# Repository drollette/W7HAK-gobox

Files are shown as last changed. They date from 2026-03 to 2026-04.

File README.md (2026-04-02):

# W7HAK Go Box Telemetry System

A field-deployable amateur radio go box (callsign **W7HAK**) with real-time battery telemetry, environmental monitoring, and a local Grafana dashboard accessible over a USB gadget-mode connection.

---

## Hardware Architecture

| Component | Role |
|---|---|
| Raspberry Pi Zero W | Single-board computer running telemetry daemon, InfluxDB, and Grafana |
| 4S3P 45 Ah LiFePO4 pack | Primary power (nominal 12.8 V, 576 Wh) using 33140-format cells |
| ADS1115 (I2C 0x48) | 16-bit ADC reading four cell-tap voltages via resistor ladder |
| 2x INA226 (I2C 0x40, 0x41) | High-side current/power monitors for solar input and system load |
| DS18B20 (GPIO 4, 1-Wire) | Ambient and cell temperature sensors |
| DC Fuse Block (marine-grade) | Central power distribution with individually fused load circuits |
| RF-silent 12V DC fan | Enclosure cooling, activated by hardware thermal switch |
| Normally-open thermal switch | Ambient temperature failsafe — engages fan at ~45 °C without GPIO control |
| DC-DC Buck-Boost Charge Controller | LTC3780 10A converter tuned to 14.6V CV / 5A CC LiFePO4 profile |

### Power Distribution & Charging

All system power flows from the battery through a single monitored path before reaching the fuse block. An **LTC3780 10A Buck-Boost Converter** allows charging from any unconditioned DC source (12V automotive charger, vehicle accessory port, generic power supply) via an Anderson Powerpole input connector. The LTC3780 is physically calibrated to a **14.6V CV / 5A CC** LiFePO4 charging profile using its onboard potentiometers (see [Charging Calibration](#charging-calibration) below).

```text
                        [External Universal DC Input Port]
                                       |
                                  [15A Fuse]
                                       |
                +---------------------------------------------+
                |     LTC3780 10A Buck-Boost Converter        |
                |   (Tuned to 14.6V CV / 5A CC via Pots)      |
                +---------------------------------------------+
                           |                       |
                     (Positive Out)          (Negative Out)
                           |                       |
                           +-------[ 1000µF ]------+  <-- (Differential Noise Filter)
                           |                       |
                           +-------[ 0.1µF  ]------+  <-- (High-Freq Bypass)
                           |                       |
                           |                       |
                        ===============================
                       ||  Solid Ferrite Bead(s)      ||  <-- (Common-Mode Filter)
                       || (Both wires pass through!)  ||
                        ===============================
                           |                       |
                       [15A Fuse]                  |
                           |                       |
                           v                       |
[4S LiFePO4 Battery] -> [BMS] -> [Main Shunt] <----+ (Negative connects here)
                                       |
                               [25A Main Fuse]
                                       |
    =========================================================================
    ||                        12V DC FUSE BLOCK                            ||
    =========================================================================
          |              |              |                 |
     (10A G90)     (3A Buck/Pi)    (1A Fan)         (1A Telemetry)
```

| Circuit | Fuse | Notes |
|---|---|---|
| Xiegu G90 Transceiver | 10A blade | ~8A peak at 20W transmit |
| Raspberry Pi (12V-to-5V buck converter) | 3A blade | Protects 12V input side of converter |
| RF-silent fan + thermal switch | 1A blade | Fan draws < 0.3A; thermal switch in series |
| Telemetry sensors / microcontrollers | 1A blade | ADS1115, INA226, DS18B20 circuits |

All loads **must** be individually fused on this block. See [wiring_diagrams/WIRING_GUIDE.md](wiring_diagrams/WIRING_GUIDE.md) for complete routing details.

### Universal DC Charging

The system accepts a wide range of DC inputs (10–30V) via an external **Anderson Powerpole** connection on the enclosure panel. This input is routed through a **15A inline fuse** to an **LTC3780 10A Buck-Boost Converter** physically calibrated to a **14.6V CV / 5A CC** LiFePO4 charging profile.

Key design points:

- The LTC3780 output is filtered by a **high-current LC Pi-Filter** that eliminates both differential and common-mode RF switching noise before it reaches the Xiegu G90:
  - **Stage 1 (Differential):** A 1000µF electrolytic capacitor and 0.1µF ceramic capacitor are soldered in parallel directly across the LTC3780 OUT terminals, absorbing voltage ripple and high-frequency spikes.
  - **Stage 2 (Common-Mode):** Both positive and negative output wires pass together through solid ferrite bead(s), suppressing common-mode noise that would otherwise radiate from the cable runs.
- The filtered **positive output** passes through a **15A inline fuse** before connecting to the main positive bus (battery side of the 25A main fuse).
- The filtered **negative output** connects to the **system/load side of the main current shunt** — not directly to the battery terminal. This ensures the System INA226 sees bidirectional current (positive = discharge, negative = charge), enabling the telemetry system to track charge current.
- The LTC3780 is housed in a **3D-printed protective enclosure** lined with **copper foil tape** on the inside surfaces to form a Faraday cage, suppressing radiated emissions.

**The negative output of the LTC3780 must pass through the main shunt. Do not wire it directly to the battery's negative terminal, or the telemetry script will not register the incoming charging current.**

### Thermal Management — RF-Silent Fan & Thermal Switch

An RF-silent 12V DC fan provides enclosure cooling. The fan is controlled entirely in hardware by a **normally-open (NO) thermal switch** wired in series on a dedicated 1A fused circuit from the DC fuse block. When the ambient enclosure temperature reaches approximately **45 °C**, the thermal switch closes and the fan runs.

This design is intentional: the thermal switch acts as an automatic hardware-level failsafe that does **not** require Raspberry Pi GPIO control or any software switching logic. This keeps RF noise from PWM or digital switching to an absolute minimum — critical for a ham radio go box operating on HF.

The DS18B20 ambient temperature sensor (read by `telemetry.py`) monitors the same enclosure environment. When telemetry readings approach 45 °C, the fan should be observed activating independently via the thermal switch.

### Bill of Materials

For a complete list of hardware, sensors, and passive components required to build this system, please see the [Bill of Materials (BOM)](BOM.md).

### Voltage Measurement — Resistor Ladder

The ADS1115 cannot safely measure the full pack voltage directly. A resistor ladder divides each cell-stack tap down to a range the ADC can read. The `telemetry.py` script applies the following multipliers to recover actual stack voltages, then uses subtraction to isolate each cell:

| Channel | Tap | Multiplier |
|---|---|---|
| AIN0 | Cell 1 top | 2.0 |
| AIN1 | Cell 2 top | 3.2 |
| AIN2 | Cell 3 top | 4.3 |
| AIN3 | Cell 4 top (pack +) | 5.7 |

See `/wiring_diagrams/ads1115_resistor_ladder_schematic.svg` for the full schematic.

### Analog Signal Filtering

Each resistor ladder output passes through a hardware RC low-pass filter before reaching the ADS1115 ADC input. This eliminates switching noise from the LTC3780 charger and other RF sources at the hardware level, producing clean readings without aggressive software filtering.

```text
[Battery Cell Tap] or [Shunt Sensor Out]
         |
         | (Raw, noisy analog signal)
         |
         +-----[ 1kΩ Resistor ]-----+---------> To ADC Input Pin / GPIO
                                    |
                                    +---[ 10µF Capacitor ]---+
                                    |                        |
                                    +---[ 0.1µF Ceramic ]----+
                                                             |
                                                             v
                                                    [ Telemetry Ground ]
```

The 1kΩ / 10µF filter provides a -3dB cutoff at ~16 Hz — well above the 0.1 Hz sample rate but far below the LTC3780 switching frequency (~300 kHz). The parallel 0.1µF ceramic capacitor extends high-frequency rejection. All capacitors must be rated **25V minimum** (the pack reaches 14.6V at full charge). See [wiring_diagrams/WIRING_GUIDE.md](wiring_diagrams/WIRING_GUIDE.md) Section 6a for detailed construction instructions.

### Wiring & Schematics

Complete pin-by-pin wiring instructions — including the 12V fuse block topology, custom USB-C bulkhead wiring, and RFI mitigation techniques — can be found in [wiring_diagrams/WIRING_GUIDE.md](wiring_diagrams/WIRING_GUIDE.md).

---

## Accessing the Dashboard (USB Gadget Mode)

The Pi Zero W is configured as a USB OTG gadget. When connected to a laptop via the data USB port:

1. The Pi enumerates as a USB Ethernet adapter (`usb0`).
2. The Pi's static IP on that interface is `192.168.7.2`.
3. Navigate to `http://192.168.7.2:3000` in a browser to open Grafana.
4. InfluxDB listens on `http://192.168.7.2:8086`.

No Wi-Fi or external network is required in the field.

### Enabling USB Gadget Mode on the Pi Zero W

Perform these steps once on the Pi before first use:

**1. Enable the `dwc2` overlay** — append to `/boot/config.txt`:
```
dtoverlay=dwc2
```

**2. Load the `g_ether` module at boot** — in `/etc/modules`, add a new line:
```
g_ether
```

**3. Assign a static IP to `usb0`** — append to `/etc/dhcpcd.conf`:
```
interface usb0
static ip_address=192.168.7.2/24
```

**4. On your laptop**, configure the USB Ethernet adapter that appears with a manual IP in the same subnet, e.g. `192.168.7.1/24`. No DHCP server is needed.

**5. Reboot the Pi.** The `usb0` interface will come up automatically on every subsequent boot.

---

## Installation

### 1. Prepare the Pi

Enable **I2C** and **1-Wire** before running the setup script:

```bash
sudo raspi-config
# Interface Options → I2C → Enable
# Interface Options → 1-Wire → Enable
# Reboot
```

### 2. Clone the repository

```bash
cd /home/pi
git clone https://github.com/drollette/W7HAK-gobox.git
cd W7HAK-gobox
```

### 3. Run the setup script

```bash
sudo bash scripts/setup_pi.sh
```

This will:
- Install system packages (`python3-pip`, `i2c-tools`, `python3-smbus`)
- Install Python libraries from `requirements.txt` via `pip3 install -r requirements.txt`
- Install, enable, and start the `gobox_telemetry` systemd service

### 4. Verify the service

```bash
sudo systemctl status gobox_telemetry.service
sudo journalctl -u gobox_telemetry.service -f
```

---

## Service Management

| Command | Action |
|---|---|
| `sudo systemctl start gobox_telemetry` | Start the telemetry daemon |
| `sudo systemctl stop gobox_telemetry` | Stop the telemetry daemon |
| `sudo systemctl restart gobox_telemetry` | Restart after config changes |
| `sudo systemctl disable gobox_telemetry` | Prevent autostart on boot |

---

## Calibration

Because 1% tolerance resistors and shunt components still vary slightly, the default multipliers and correction factor in `telemetry.py` will likely need to be tuned to your specific hardware to get pinpoint accuracy.

### When to Calibrate

- After initial assembly, before first deployment
- After replacing any resistors in the voltage divider ladder
- After replacing the INA226 shunt resistor
- If Grafana cell voltage readings drift from multimeter measurements

### Live Sensor Monitor

Before running the interactive calibration, use `test_sensors.py` to verify all sensors are wired correctly and producing plausible readings. It prints a live, auto-refreshing readout of all cell voltages, INA226 current/power, and DS18B20 temperatures every second:

```bash
python3 scripts/test_sensors.py
```

Press `Ctrl+C` to quit. This tool is also useful during bench testing to watch values change in real time as you adjust loads or connections.

### Running the Calibration Script

The interactive `calibrate.py` script automates the entire process:

```bash
cd /home/pi/W7HAK-gobox
python3 scripts/calibrate.py
```

The script will walk you through two steps:

**Step 1 — Cell Voltage Calibration**

You will need a calibrated digital multimeter (DMM).

1. Set your DMM to **DC Voltage (VDC)**, typically the 20V range.
2. Connect the **BLACK (negative) probe to the battery's main negative terminal** (Pack -). Leave it there for all four measurements.
3. Move the **RED (positive) probe** to each successive BMS cell tap, from Cell 1 through Cell 4 (Pack +), entering each cumulative stack voltage when prompted.
4. Readings should increase with each tap — roughly 3.3V, 6.6V, 9.9V, and 13.2V for a healthy 4S LiFePO4 pack.

The script reads the current ADS1115 tap voltages and computes corrected `CELL_MULTIPLIERS` using:

```
New Multiplier = True Stack Voltage / Raw Tap Voltage
```

**Step 2 — Shunt Resistance Calibration**

1. **Completely disconnect power from the system** before measuring.
2. Set your DMM to the **lowest Ohms/Resistance setting** (milliohms if available).
3. Short the leads together and zero the meter.
4. Measure the resistance directly across the shunt resistor terminals.
5. Enter the reading in Ohms (e.g., `0.0015` for a 1.5 milliohm shunt).

The script computes a new `CORRECTION_FACTOR` based on the nominal 2 milliohm shunt:

```
CORRECTION_FACTOR = 0.002 / Measured Resistance
```

**Step 3 — Apply Changes**

The script writes the updated `CELL_MULTIPLIERS` and `CORRECTION_FACTOR` directly to `scripts/telemetry.py`. Restart the service to apply:

```bash
sudo systemctl restart gobox_telemetry
```

### Manual Calibration

If you prefer to calibrate manually, measure the DC voltage from battery ground (Pack -) to each cell tap, then calculate:

```
New Multiplier = Current Multiplier × (True Voltmeter Voltage ÷ Calculated Stack Voltage)
```

Edit `CELL_MULTIPLIERS` in `scripts/telemetry.py` and restart the service.

---

## Charging Calibration

The LTC3780 buck-boost converter must be physically calibrated with a multimeter **before the battery is ever connected to the output**. This sets the constant-voltage (CV) ceiling and constant-current (CC) limit for a safe 4S LiFePO4 charge profile.

You will need:
- A 12V DC power source (bench supply, automotive battery, or wall adapter)
- A digital multimeter (DMM) with a **10A DC current range**
- A small flathead or Phillips screwdriver for the trimpots

### Step 1: Constant Voltage (CV) Tuning

1. **Do not connect the battery to the LTC3780 output.**
2. Connect a 12V power source to the LTC3780 **IN** terminals (observe polarity).
3. Set the multimeter to **DC Voltage** and connect the probes to the LTC3780 **OUT** terminals.
4. Slowly turn the **CV potentiometer** with a small screwdriver until the multimeter reads exactly **14.6V**.
5. This sets the voltage ceiling for 4S LiFePO4 (3.65V per cell).

### Step 2: Constant Current (CC) Tuning

1. Disconnect the multimeter from voltage mode.
2. Turn the **CC potentiometer counter-clockwise approximately 20 turns** to lower the current limit to its minimum.
3. Switch the multimeter to the **10A DC Current** setting and move the red probe to the **10A jack** on the meter.
4. Touch the multimeter probes directly to the LTC3780 **OUT** terminals (this creates a short circuit through the meter's internal shunt — this is safe because the CC limit is set to minimum).
5. Slowly turn the **CC potentiometer clockwise** until the multimeter reads exactly **5.00A**.
6. This limits the charge current to 5A, preventing overload on small external power supplies and keeping the charge rate within safe bounds for the battery pack.

### Step 3: Verify and Install

1. Disconnect the 12V source.
2. Reconfigure the multimeter back to standard DC Voltage mode.
3. The LTC3780 is now locked to a **14.6V / 5A** LiFePO4 CC/CV charging profile.
4. Install the module in its shielded 3D-printed enclosure and connect per the [Wiring Guide](wiring_diagrams/WIRING_GUIDE.md).

---

## Repository Layout

```
goBox/
├── 3d_models/          # ABS compression-frame parts for the battery pack
├── pcb/
│   └── w7hak_hat/      # KiCad project for custom Pi Zero W telemetry HAT
├── wiring_diagrams/    # Schematics (resistor ladder, INA226 hookup)
├── scripts/
│   ├── telemetry.py    # Main telemetry daemon
│   ├── calibrate.py    # Interactive calibration utility
│   ├── test_sensors.py # Live sensor monitor for bench testing and calibration
│   └── setup_pi.sh     # One-shot provisioning script
└── systemd/
    └── gobox_telemetry.service   # systemd unit file
```

---

## 3D Models

The files in `/3d_models` are STEP files designed for **ABS filament** and printed on a Bambu Lab printer. They are specifically engineered for the dimensional tolerances of ABS (higher thermal stability, post-process acetone smoothing). Do not substitute PLA or PETG without re-evaluating clearances and structural load paths.

| File | Description |
|---|---|
| `33140_3S_4P_CENTER.step` | Center compression frame for 3P cell group |
| `33140_3S_4P_END_CAP.step` | End cap for the 4S3P pack assembly |

A custom protective enclosure for the bare LTC3780 PCB should be 3D printed on the Bambu Lab printer in ABS. **Line the inside of the enclosure with copper foil tape** (with conductive adhesive) to form a Faraday cage that suppresses switching noise before it radiates into the HF environment. Ground the copper lining to the system negative bus.

---

## License

Released for amateur radio and personal use. No warranty. 73 de W7HAK.

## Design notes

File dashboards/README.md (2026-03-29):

Place exported Grafana dashboard JSON files here.

## w7hak_telemetry_dashboard.json

Starter dashboard with four panels: LiFePO4 cell voltages, thermal sensors, system power draw, and solar input.

To use this dashboard:
1. Open your Grafana instance (e.g., `http://192.168.7.2:3000`).
2. Go to Dashboards -> Import.
3. Upload `w7hak_telemetry_dashboard.json` or paste its contents.
4. Select your local InfluxDB data source when prompted.

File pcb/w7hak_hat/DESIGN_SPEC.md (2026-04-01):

# W7HAK Telemetry HAT — PCB Design Specification

Custom Pi Zero W HAT implementing the 4-channel cell voltage monitor with RC filters from the project schematic.

## Board Specifications

| Parameter | Value |
|---|---|
| Board dimensions | 65mm × 30mm |
| Layers | 2 (F.Cu / B.Cu) |
| Board thickness | 1.6mm (standard) |
| Copper weight | 1 oz (35µm) |
| Min trace width | 0.25mm (10 mil) |
| Min clearance | 0.2mm (8 mil) |
| Min drill | 0.3mm |
| Surface finish | HASL or ENIG |
| Solder mask | Both sides (green) |
| Silkscreen | Front side |

## Mounting Holes

4x M2.5 through-holes matching the Pi Zero W mounting pattern:

| Hole | X (mm) | Y (mm) |
|---|---|---|
| MH1 | 3.5 | 3.5 |
| MH2 | 61.5 | 3.5 |
| MH3 | 3.5 | 26.5 |
| MH4 | 61.5 | 26.5 |

Drill: 2.7mm, annular ring: 5.5mm pad.

## Connectors

### J1 — BMS Battery Taps (JST-XH 5-pin, right-angle or vertical)

**Footprint:** JST_XH_B5B-XH-A_1x05_P2.50mm_Vertical

| Pin | Signal | Wire Color (suggested) |
|---|---|---|
| 1 | Cell 4 tap (14.4V nominal) | Red |
| 2 | Cell 3 tap (10.8V nominal) | Orange |
| 3 | Cell 2 tap (7.2V nominal) | Yellow |
| 4 | Cell 1 tap (3.6V nominal) | Green |
| 5 | Telemetry Ground (Node B) | Black |

**Placement:** Left edge of board, centered vertically (~Y=15mm).

### J2 — ADS1115 ADC Module (JST-XH 6-pin, right-angle or vertical)

**Footprint:** JST_XH_B6B-XH-A_1x06_P2.50mm_Vertical

| Pin | Signal |
|---|---|
| 1 | A0 (from Cell 1 RC filter output) |
| 2 | A1 (from Cell 2 RC filter output) |
| 3 | A2 (from Cell 3 RC filter output) |
| 4 | A3 (from Cell 4 RC filter output) |
| 5 | VDD (3.3V from Pi Pin 1) |
| 6 | GND (Telemetry Ground) |

**Placement:** Right edge of board, centered vertically (~Y=15mm).

### J3 — Raspberry Pi GPIO Header (2×20 pin female header)

**Footprint:** PinSocket_2x20_P2.54mm_Vertical

**Placement:** Bottom edge, centered horizontally. Pin 1 at left side (X≈11.5mm, Y≈26mm).

## Circuit — Resistor Ladder + RC Filters

### Per-Channel Signal Path

For each of the 4 channels (Cell 1 through Cell 4):

```
J1 pin ──→ [Rs: Series Resistor] ──┬── [Rf: 1kΩ Filter Resistor] ──┬──→ J2 pin (ADC input)
                                    │                                │
                                  [Rsh: 10kΩ Shunt]                [C1: 10µF 25V]
                                    │                                │
                                    └── GND                        [C2: 0.1µF]
                                                                     │
                                                                    GND
```

### Component Values Per Channel

| Channel | Cell Tap | Series R (Rs) | Shunt R (Rsh) | Filter R (Rf) | C1 | C2 | ADC Pin |
|---|---|---|---|---|---|---|---|
| CH4 | Cell 4 (14.4V) | Rs1 = 47kΩ 1% | Rsh1 = 10kΩ 1% | Rf1 = 1kΩ 1% | C1 = 10µF/25V | C5 = 0.1µF | A3 |
| CH3 | Cell 3 (10.8V) | Rs2 = 33kΩ 1% | Rsh2 = 10kΩ 1% | Rf2 = 1kΩ 1% | C2 = 10µF/25V | C6 = 0.1µF | A2 |
| CH2 | Cell 2 (7.2V) | Rs3 = 22kΩ 1% | Rsh3 = 10kΩ 1% | Rf3 = 1kΩ 1% | C3 = 10µF/25V | C7 = 0.1µF | A1 |
| CH1 | Cell 1 (3.6V) | Rs4 = 10kΩ 1% | Rsh4 = 10kΩ 1% | Rf4 = 1kΩ 1% | C4 = 10µF/25V | C8 = 0.1µF | A0 |

### Additional Components

| Ref | Value | Purpose | Connection |
|---|---|---|---|
| C9 | 0.1µF ceramic | ADS1115 VDD decoupling | Between J2 pin 5 (VDD) and J2 pin 6 (GND) |
| R_PU | 4.7kΩ | DS18B20 1-Wire pull-up | Between Pi Pin 1 (3.3V) and Pi Pin 7 (GPIO 4) |

## Resistor Footprints

All resistors: **0805 SMD** (2012 metric) or **through-hole axial** (choose one consistently).

- For easier hand-soldering: use through-hole axial (Resistor_THT:R_Axial_DIN0207_L6.3mm_D2.5mm_P10.16mm_Horizontal)
- For compact layout: use 0805 SMD (Resistor_SMD:R_0805_2012Metric)

## Capacitor Footprints

- **10µF / 25V:** Through-hole radial electrolytic (Capacitor_THT:CP_Radial_D5.0mm_P2.50mm) or ceramic 1206 SMD if available at 25V.
- **0.1µF ceramic:** 0805 SMD (Capacitor_SMD:C_0805_2012Metric) or through-hole (Capacitor_THT:C_Disc_D3.0mm_W1.6mm_P2.50mm).

## GPIO Pin Usage

| Pi Pin | GPIO | Function | Connection |
|---|---|---|---|
| 1 | 3.3V Power | VDD | J2 pin 5 (ADS1115 VDD), R_PU (pull-up) |
| 3 | GPIO 2 (SDA) | I2C Data | Route to J2 (connect externally to ADS1115 SDA) |
| 5 | GPIO 3 (SCL) | I2C Clock | Route to J2 (connect externally to ADS1115 SCL) |
| 7 | GPIO 4 | 1-Wire | R_PU pull-up to 3.3V (for DS18B20) |
| 9 | GND | Ground | Telemetry ground plane, J1 pin 5, J2 pin 6 |

All other GPIO pins are passed through (directly connected pin-to-pin on the 2×20 header).

## Layout Guidelines

1. **Ground plane:** Pour a ground fill on the back copper layer (B.Cu) tied to the telemetry ground net. This provides a low-impedance return path and RF shielding.
2. **RC filter placement:** Place Rf and the capacitor pair (C1 + C2) as close to the J2 (ADC) connector as physically possible. Short traces between the filter caps and the ADC input minimize noise pickup.
3. **Divider placement:** Place Rs and Rsh in the middle zone between J1 and J2.
4. **Decoupling cap C9:** Place directly adjacent to J2 pins 5 and 6.
5. **Keep analog traces away from the GPIO header** to minimize digital noise coupling.
6. **Trace widths:** 0.25mm for signal traces, 0.5mm for power (3.3V, GND).

## Generating Gerber Files

After completing the layout in KiCad:

1. Open the PCB editor
2. File → Plot (or Fabrication → Plot)
3. Select layers: F.Cu, B.Cu, F.SilkS, B.SilkS, F.Mask, B.Mask, Edge.Cuts
4. Output format: Gerber
5. Output directory: `gerbers/`
6. Click "Plot"
7. Then click "Generate Drill Files" → Excellon format
8. Upload the `gerbers/` folder to your PCB fab (JLCPCB, PCBWay, OSH Park, etc.)

## Bill of Materials (PCB-specific)

| Qty | Reference | Value | Package | Notes |
|---|---|---|---|---|
| 1 | Rs1 | 47kΩ 1% | 0805 or axial | Series divider, Cell 4 |
| 1 | Rs2 | 33kΩ 1% | 0805 or axial | Series divider, Cell 3 |
| 1 | Rs3 | 22kΩ 1% | 0805 or axial | Series divider, Cell 2 |
| 1 | Rs4 | 10kΩ 1% | 0805 or axial | Series divider, Cell 1 |
| 4 | Rsh1–Rsh4 | 10kΩ 1% | 0805 or axial | Shunt resistors |
| 4 | Rf1–Rf4 | 1kΩ 1% | 0805 or axial | RC filter series |
| 1 | R_PU | 4.7kΩ | 0805 or axial | 1-Wire pull-up |
| 4 | C1–C4 | 10µF / 25V | Radial 5mm or 1206 | RC filter bulk |
| 5 | C5–C9 | 0.1µF | 0805 or disc | RF bypass + decoupling |
| 1 | J1 | JST-XH 5-pin | B5B-XH-A | BMS battery taps |
| 1 | J2 | JST-XH 6-pin | B6B-XH-A | ADS1115 interface |
| 1 | J3 | 2×20 female header | 2.54mm pitch | Pi GPIO |
| 4 | MH1–MH4 | M2.5 mounting hole | 2.7mm drill | Board mounting |

**Total: 14 resistors, 9 capacitors, 3 connectors, 4 mounting holes**

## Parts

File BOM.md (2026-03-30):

# W7HAK Go Box: Bill of Materials (BOM)

This is the complete parts list required to build the Pi Zero W telemetry system and the 4S LiFePO4 power distribution network.

## 1. Enclosure & Mounting

* **Enclosure:** Weatherproof rugged hard case (Size to fit your specific battery and radio dimensions. Ensure adequate depth for 33140 cells).
* **Faceplate/Deck:** ABS or Aluminum sheet, cut to fit the internal lip of the enclosure.
* **Stand-offs & Hardware:** M2.5 brass standoffs (for the Pi) and assorted M3/M4 stainless steel hardware for structural mounting.

## 2. Compute & Telemetry Brain

* **Microcontroller:** Raspberry Pi Zero W (Original, single-core is sufficient).
* **Prototyping Board:** MakerSpot Protoboard Breadboard HAT (or similar Pi Zero footprint proto-board).
* **Storage:** High-endurance MicroSD Card (16GB or 32GB).
* **ADC Module:** Adafruit ADS1115 (16-bit I2C).
* **Power Monitors:** 2x INA226 High-Side Current/Power Sensors (I2C).
* **Temperature Sensors:** 2x DS18B20 (TO-92 package, 1-Wire).

## 3. Power Storage & Distribution

* **Battery Cells:** 12x 33140-format LiFePO4 cells (Configured as 4S3P for ~45Ah).
* **BMS:** Daly 4S 12V 60A LiFePO4 Battery Protection Board (Hardware/Common Port version).
* **Main Fuse:** 25A Inline ATC/ATO blade fuse holder (between main current shunt and DC fuse block).
* **DC Fuse Block:** 12V Marine-grade Blade Fuse Block with negative bus (minimum 4 circuits).
* **Blade Fuses (ATC/ATO):** 1x 10A (G90), 1x 3A (buck converter), 2x 1A (fan circuit, telemetry sensors).
* **Step-Down Converter:** 12V to 5V Buck Converter (Minimum 3A output).
* **DC Charge Controller:** LTC3780 10A DC-DC Buck-Boost Converter, adjustable output, physically calibrated to 14.6V CV / 5A CC (4S LiFePO4 profile). Accepts 10–30V input.
* **LTC3780 Enclosure:** Custom 3D-printed protective case (ABS, Bambu Lab printer). Line interior with copper foil tape to form a Faraday cage for RFI suppression.
* **Charger Input Fuse:** 15A Inline ATC/ATO blade fuse holder (on charger positive input lead).
* **Charger Output Fuse:** 15A Inline ATC/ATO blade fuse holder (on charger positive output lead).
* **Wire:** 10 AWG silicone wire (Main power runs), 22 AWG solid-core wire (Telemetry).

## 4. Thermal Management

* **Cooling Fan:** RF-silent 12V DC brushless fan (sized for enclosure; typical draw < 0.3A).
* **Thermal Switch:** Normally-open (NO) bimetallic thermal switch, ~45 °C activation (KSD9700 series or equivalent, rated for 12V DC).
* **Note:** The thermal switch is wired in series with the fan on a dedicated 1A fused circuit. No GPIO or software control is used — the switch engages automatically at ambient temperature threshold.

## 5. Passive Components & RFI Mitigation

* **Resistor Ladder (1% Precision Metal Film):**
  * 4x 10kΩ
  * 1x 22kΩ
  * 1x 33kΩ
  * 1x 47kΩ
* **Pull-up Resistor:** 1x 4.7kΩ (For DS18B20 1-Wire bus).
* **Decoupling Capacitor:** 1x 0.1µF (104) Ceramic Capacitor (ADS1115 VDD/GND decoupling).
* **RC Low-Pass Filters (per analog signal line):**
  * 4x 1kΩ Resistors (1/4 Watt) — one per cell tap line to ADS1115 inputs A0–A3.
  * 4x 10µF Capacitors (minimum **25V rating**, ceramic or electrolytic). The 25V+ rating is critical because the 4S LiFePO4 pack reaches 14.6V at full charge, which would stress standard 16V capacitors.
  * 4x 0.1µF (104) Ceramic Capacitors — high-frequency RF decoupling, wired in parallel with the 10µF capacitors.
* **LTC3780 Output LC Filter:**
  * 1x 1000µF Electrolytic Capacitor (minimum **25V rating**). Differential noise filter soldered across LTC3780 OUT terminals.
  * 1x 0.1µF (104) Ceramic Capacitor. High-frequency bypass soldered in parallel with the 1000µF cap across LTC3780 OUT terminals.
  * 2–3x Small Solid Ferrite Beads (approx. 1cm inner diameter). Common-mode choke — both positive and negative output wires pass through together. Use multiple beads back-to-back if a single bead is too tight for the wire pair.
* **RFI Chokes (Snap-on):** Mix 31 Snap-on Ferrite Beads (Sized for 5V Pi power line and solar input).
* **Shielding:** Copper foil tape with conductive adhesive.

## 6. Panel Connectors

* **Gadget Mode Data:** USB-C Panel Mount / Bulkhead Connector (with breakout pads for D+/D-).
* **DC Charge Input:** Anderson PowerPole panel mount connector pair (30A-rated contacts) for external DC charging.
* **Power Outputs:** Anderson PowerPole panel mounts and/or 12V Marine "Cigarette" sockets.

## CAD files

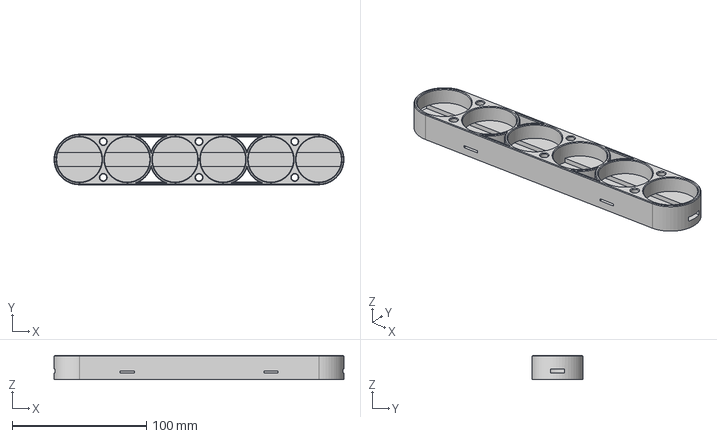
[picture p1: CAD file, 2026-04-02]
3d_models/33140_3S_4P_END_CAP.step
215.9 x 37.7 x 18.0 mm

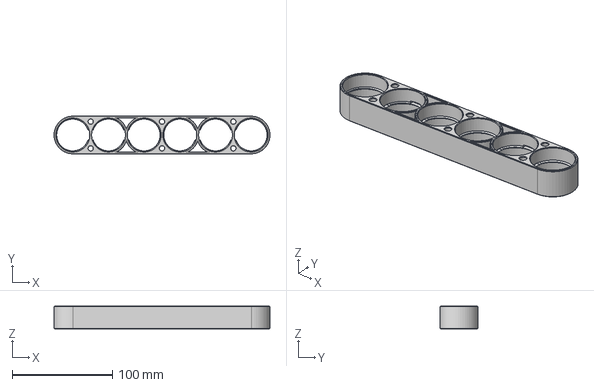
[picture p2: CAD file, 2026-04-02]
3d_models/33140_3S_4P_CENTER.step
215.9 x 37.7 x 22.5 mm

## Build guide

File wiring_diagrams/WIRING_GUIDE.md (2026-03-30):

# W7HAK Go Box: Master Wiring Guide (Pi Zero W Direct Telemetry)

## 1. 12V Power Distribution & Fuse Block

All system power originates from the 4S LiFePO4 battery and is routed through a single monitored path before reaching a central DC fuse block. Every load is individually fused.

### Power Flow Path (Discharge)

```
Battery Pack (+) → BMS Output (+) → 25A Main Inline Fuse → System INA226 (IN+)
System INA226 (IN-) → DC Fuse Block Positive (+) Feed

Battery Pack (-) → BMS Output (-) → Main Current Shunt → DC Fuse Block Negative (-) Bus
```

The Main Current Shunt sits on the negative rail between the BMS output and the fuse block negative bus. All load current and charge current flows through this shunt, enabling the System INA226 to read **bidirectional current** (positive values = discharge/load, negative values = incoming charge).

### Charging Path (DC Input)

```
External Anderson Powerpole (+) → 15A Input Fuse → LTC3780 IN (+)
External Anderson Powerpole (-) → LTC3780 IN (-)

LTC3780 OUT (+/−) → LC Pi-Filter (see Section 8) → 15A Output Fuse (positive) → Main Positive Bus
                                                   → (negative) System/Load side of Main Current Shunt
```

**The negative output of the LTC3780 must pass through the main shunt. Do not wire it directly to the battery's negative terminal, or the telemetry script will not register the incoming charging current.**

The LTC3780 10A Buck-Boost Converter is physically calibrated to **14.6V CV / 5A CC** (4S LiFePO4 profile) using its onboard potentiometers. It accepts 10–30V DC input from automotive chargers, vehicle accessory ports, or generic power supplies. See the Charging Calibration section in the README for the calibration procedure.

### Fuse Block Circuit Assignments

Wire each load to its own fused circuit on the DC fuse block:

| Fuse Block Circuit | Fuse | Load |
|---|---|---|
| Circuit 1 | **10A** blade | Xiegu G90 Transceiver (~8A peak at 20W TX) |
| Circuit 2 | **3A** blade | 12V-to-5V Buck Converter (Pi + sensors on 5V rail) |
| Circuit 3 | **1A** blade | RF-silent fan + thermal switch (see Section 7) |
| Circuit 4 | **1A** blade | Telemetry sensors / microcontrollers (direct 12V devices) |

**Important:** All loads must be individually fused on the distribution block. Do not bypass the fuse block by wiring loads directly to the battery or shunt output.

---

## 2. 5V Power Foundation (Pi & Sensors)

The Raspberry Pi Zero W and all sensors operate on 3.3V logic. Power is supplied via a 12V-to-5V Buck Converter, which acts as an accessory on the fuse block.

* **Buck Converter Input:** Wire to a low-amp (e.g., 3A) circuit on the 12V Fuse Block.
* **Pi Pin 2 (5V):** Connect to Buck Converter Positive (+) Output.
* **Pi Pin 6 (GND):** Connect to Buck Converter Negative (-) Output.
* **RFI Protection:** Snap a Mix 31 ferrite bead on the 5V line near the Pi. Wrap the buck converter in grounded copper tape.

---

## 3. I2C Bus (Power & Cell Monitoring)

Daisy-chain the ADS1115 and both INA226 modules to the Pi's I2C pins.

* **Pi Pin 3 (SDA):** Connect to SDA on ADS1115, INA226 (Solar), and INA226 (System).
* **Pi Pin 5 (SCL):** Connect to SCL on ADS1115, INA226 (Solar), and INA226 (System).
* **ADS1115 Power:** VDD to Pi Pin 1 (3.3V), GND to Pi Pin 9. **Critical:** Solder a 0.1µF ceramic decoupling capacitor directly across VDD and GND on the ADS1115 to filter RF noise.
* **INA226 Addressing:**
  * Solar INA226: Address 0x40 (Default).
  * System INA226: Address 0x41 (Solder the A0 pad).

---

## 4. 1-Wire Bus (Temperature Sensors)

Wire all DS18B20 sensors in parallel.

* **Sensor GND (Pin 1):** Connect to Pi Pin 14 (GND).
* **Sensor DQ / Data (Pin 2):** Connect to Pi Pin 7 (GPIO 4).
* **Sensor VDD (Pin 3):** Connect to Pi Pin 1 (3.3V).
* **Pull-Up Resistor:** Solder a 4.7kΩ resistor between Pin 1 (3.3V) and Pin 7 (GPIO 4).

---

## 5. Custom USB-C Bulkhead (Gadget Mode)

To use a panel-mount USB-C connection instead of the fragile micro-USB port, solder to the test pads on the bottom of the Pi Zero W.

* **PP1 (5V):** USB-C VBUS
* **PP6 (GND):** USB-C GND
* **PP22 (D+):** USB-C D+ (Must be twisted with D- to reject RFI)
* **PP23 (D-):** USB-C D- (Must be twisted with D+ to reject RFI)

---

## 6. Cell Voltage Resistor Ladder

(See `ads1115_resistor_ladder_schematic.svg` for the visual diagram.)

Use 1% precision resistors. Build the ladder on a MakerSpot Protoboard HAT.

* **Cell 1 (3.6V):** To ADS1115 A0 via 10k/10k divider.
* **Cell 2 (7.2V):** To ADS1115 A1 via 22k/10k divider.
* **Cell 3 (10.8V):** To ADS1115 A2 via 33k/10k divider.
* **Cell 4 (14.4V):** To ADS1115 A3 via 47k/10k divider.

Each divider output passes through an RC low-pass filter before reaching the ADS1115 input pin. See Section 6a below.

---

## 6a. Telemetry RC Low-Pass Filters

All analog signal lines between the resistor ladder and the ADS1115 ADC inputs must be filtered with hardware-level RC low-pass filters. These smooth sensor data and shunt RF noise before it reaches the ADC, eliminating high-frequency interference that would otherwise corrupt voltage readings — especially when the LTC3780 charger or other switching converters are active.

### Filter Topology

```text
=== TELEMETRY RC LOW-PASS FILTER TOPOLOGY ===

[Battery Cell Tap] or [Shunt Sensor Out]
         |
         | (Raw, noisy analog signal)
         |
         +-----[ 1kΩ Resistor ]-----+---------> To ADC Input Pin / GPIO
                                    |
                                    +---[ 10µF Capacitor ]---+
                                    |                        |
                                    +---[ 0.1µF Ceramic ]----+
                                                             |
                                                             v
                                                    [ Telemetry Ground ]
```

### Wiring Rules

1. **Resistor placement:** The 1kΩ resistor must be wired **in series** with the signal wire, as close to the ADS1115 input pin as physically possible. Solder it directly on the protoboard HAT at the ADC end of the trace, not at the battery tap end.
2. **Capacitor placement:** The 10µF capacitor must be wired **in parallel**, bridging the ADS1115 input pin directly to the telemetry common ground. Use a **minimum 25V rated** capacitor — the 4S LiFePO4 pack reaches 14.6V at full charge, which would stress standard 16V capacitors.
3. **RF decoupling:** Wire the 0.1µF ceramic capacitor **in parallel with the 10µF capacitor** (also bridging the ADC input pin to ground). The ceramic cap handles high-frequency RF noise that the larger electrolytic cannot absorb due to its parasitic inductance.
4. **Repeat for each channel:** Build one RC filter per ADS1115 input (A0–A3), for a total of 4 filters.

### Design Notes

* **Cutoff frequency:** The 1kΩ / 10µF combination yields a -3dB cutoff at approximately **16 Hz** (`f = 1 / (2π × R × C)`). This is well above the 0.1 Hz telemetry sample rate (10-second loop) but aggressively attenuates switching noise from the LTC3780 (~300 kHz) and other RF sources.
* **The 0.1µF ceramic** in parallel extends high-frequency rejection beyond what the 10µF electrolytic alone provides, creating a two-stage roll-off.
* **Ground reference:** All filter capacitors must connect to the same telemetry ground node used by the ADS1115 GND pin. Do not use separate ground points, or ground loops will introduce the noise the filter is designed to eliminate.

---

## 7. RF-Silent Fan & Thermal Switch Circuit

An RF-silent 12V DC fan provides enclosure cooling, controlled entirely by a hardware thermal switch (no GPIO, no software PWM). This keeps RF switching noise off the HF bands.

### Circuit Wiring

The fan and thermal switch are wired in series on a dedicated 1A fused circuit from the DC fuse block:

```
DC Fuse Block (Circuit 3, 1A fuse) ──(+)──→ Thermal Switch (NO) ──→ Fan (+)
Fan (-) ──→ DC Fuse Block Negative (-) Bus
```

### Component Details

* **Fan:** RF-silent 12V DC brushless fan. Mount on the enclosure wall or lid for maximum airflow across the battery pack and electronics. Typical draw < 0.3A.
* **Thermal Switch:** Normally-open (NO) bimetallic switch (e.g., KSD9700 series, 45 °C activation, rated for 12V DC). Mount inside the enclosure near the battery pack or warmest zone.

### How It Works

1. At ambient temperatures below ~45 °C, the thermal switch is **open** and the fan is off.
2. When enclosure temperature reaches ~45 °C, the thermal switch **closes**, completing the circuit and powering the fan.
3. When temperature drops below the switch's hysteresis point (typically ~35 °C), the switch opens and the fan stops.

### Design Rationale

* **No GPIO control:** The thermal switch is a passive hardware failsafe. It does not depend on the Raspberry Pi being operational or any software running. If the Pi crashes or the telemetry daemon hangs, the fan still activates.
* **No RF noise:** Bimetallic switches produce no switching transients. Unlike PWM or relay-based fan control, this approach introduces zero RF interference — critical for HF operation on the Xiegu G90.

---

## 8. Universal DC Charging Circuit (LTC3780)

The LTC3780 10A Buck-Boost Converter allows the battery to be charged from any unconditioned DC source (10–30V) via an external Anderson Powerpole connector on the enclosure panel.

### Circuit Wiring

```
Panel Anderson Powerpole (+) ──→ [15A Input Fuse] ──→ LTC3780 IN (+)
Panel Anderson Powerpole (-) ──────────────────────→ LTC3780 IN (-)

LTC3780 OUT (+) ──┬──[ 1000µF Cap ]──┬── OUT (-)
                  └──[ 0.1µF Cap  ]──┘
                  |                  |
              =============================
             || Solid Ferrite Bead(s)     ||  (Both wires pass through together!)
              =============================
                  |                  |
             [15A Output Fuse]      |
                  |                  └──→ System/Load side of Main Current Shunt
                  └──→ Main Positive Bus (battery side of 25A main fuse)
```

**The negative output of the LTC3780 must pass through the main shunt. Do not wire it directly to the battery's negative terminal, or the telemetry script will not register the incoming charging current.**

### Component Details

* **Charge Controller:** LTC3780 10A DC-DC Buck-Boost Converter, physically calibrated to **14.6V CV / 5A CC** via onboard potentiometers (see Charging Calibration in README). Accepts 10–30V input to support automotive 12V, vehicle accessory 13.8V, and bench supply sources.
* **Input Fuse:** 15A inline ATC/ATO fuse on the positive input lead. Protects the external source and wiring from a charger fault.
* **Output Fuse:** 15A inline ATC/ATO fuse on the positive output lead (after the LC filter). Protects the battery and wiring from overcurrent.
* **Panel Connector:** Anderson Powerpole connector pair mounted on the enclosure panel. Use 30A-rated contacts with 10 AWG wire for the input run.

### Output LC Pi-Filter Construction

The LTC3780 is a high-frequency switching converter and **will** radiate broadband noise across HF without proper output filtering. The LC Pi-Filter below eliminates both differential-mode and common-mode noise before it reaches the Xiegu G90.

#### Stage 1: Differential Noise Filter (Capacitors)

Solder both capacitors **in parallel** directly across the LTC3780 **OUT** terminals (positive to positive, negative to negative):

1. **1000µF electrolytic capacitor** (minimum 25V rating) — absorbs low-frequency voltage ripple and current spikes from the switching converter.
2. **0.1µF ceramic capacitor** — bypasses high-frequency RF noise that the electrolytic cannot absorb due to its parasitic inductance.

**Warning:** Observe correct polarity on the electrolytic capacitor. The positive (longer) lead connects to the LTC3780 OUT (+) terminal, and the negative (marked with a stripe) connects to OUT (−). Reversed polarity can cause the capacitor to fail or vent.

#### Stage 2: Common-Mode Filter (Ferrite Beads)

Take the positive and negative wires leaving the capacitor stage and pass them **TOGETHER** through the solid ferrite bead(s):

1. Thread both the positive and negative output wires through the center hole of a small solid ferrite bead (approx. 1cm inner diameter).
2. If the bead is too tight for multiple wraps, string **2 or 3 beads back-to-back** on the wire pair to increase impedance.

**Both the positive and negative power wires MUST pass through the exact same ferrite bead together. If you pass only one wire through, the 5A of DC charging current will instantly magnetically saturate the core, rendering it completely useless for RF filtering.** When both wires pass through together, the DC currents cancel (they flow in opposite directions), leaving only the common-mode RF noise for the ferrite to absorb.

### Additional RFI Shielding

1. **Faraday cage enclosure:** House the bare LTC3780 PCB in a 3D-printed ABS enclosure (Bambu Lab printer). Line the interior with **copper foil tape** (conductive adhesive). Ground the copper lining to the system negative bus.
2. **Snap-on ferrites:** Add Mix 31 snap-on ferrite beads to any remaining exposed leads as close to the LTC3780 as possible.
3. If interference persists during charging, disconnect the charger while operating the Xiegu G90 on receive-sensitive modes (FT8, CW, SSB).

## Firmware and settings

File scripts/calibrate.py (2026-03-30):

#!/usr/bin/env python3
"""
W7HAK Go Box Calibration Script

Calibrates the battery monitoring system by comparing user-measured multimeter
readings against the ADS1115 tap voltages, then computing corrected multipliers
and shunt correction factor. Updates telemetry.py in place.

Usage:
    python3 scripts/calibrate.py

Requirements:
    - System must be powered on with the battery connected
    - A calibrated digital multimeter (DMM)
    - Run from the repository root directory
"""

import os
import re
import sys

# ADS1115 imports — only needed when reading live tap voltages
try:
    import board
    import busio
    import adafruit_ads1x15.ads1115 as ADS
    from adafruit_ads1x15.analog_in import AnalogIn
    HAS_HARDWARE = True
except (ImportError, NotImplementedError):
    HAS_HARDWARE = False

SCRIPT_DIR = os.path.dirname(os.path.abspath(__file__))
TELEMETRY_PATH = os.path.join(SCRIPT_DIR, "telemetry.py")

NUM_CELLS = 4
CELL_VOLTAGE_MIN = 2.50
CELL_VOLTAGE_MAX = 3.65
SHUNT_MIN = 0.0001
SHUNT_MAX = 0.01
NOMINAL_SHUNT_OHMS = 0.002  # Standard INA226 shunt resistor value

# Expected stack voltage bounds at each tap (cumulative LiFePO4 cells)
STACK_MIN = [CELL_VOLTAGE_MIN * n for n in range(1, NUM_CELLS + 1)]
STACK_MAX = [CELL_VOLTAGE_MAX * n for n in range(1, NUM_CELLS + 1)]


def print_banner():
    print()
    print("=" * 60)
    print("   W7HAK Go Box  —  Calibration Utility")
    print("=" * 60)
    print()


def print_section(title):
    print()
    print("-" * 60)
    print(f"  {title}")
    print("-" * 60)
    print()


def prompt_float(prompt_text, min_val, max_val, unit_label):
    """Prompt the user for a float within the given range, retrying on bad input."""
    while True:
        raw = input(prompt_text).strip()
        try:
            value = float(raw)
        except ValueError:
            print(f"  [!] Invalid input. Please enter a numeric value.\n")
            continue

        if value < min_val or value > max_val:
            print(f"  [!] Value {value} {unit_label} is outside the expected range")
            print(f"      of {min_val} to {max_val} {unit_label}.")
            print(f"      Please re-measure and try again.\n")
            continue

        return value


def read_tap_voltages():
    """Read raw ADS1115 tap voltages from hardware."""
    i2c = busio.I2C(board.SCL, board.SDA)
    ads = ADS.ADS1115(i2c, address=0x48)
    ads.gain = 1  # +/-6.144 V range

    taps = [
        AnalogIn(ads, ADS.P0).voltage,
        AnalogIn(ads, ADS.P1).voltage,
        AnalogIn(ads, ADS.P2).voltage,
        AnalogIn(ads, ADS.P3).voltage,
    ]
    return taps


def prompt_tap_voltages():
    """Prompt user to manually enter the raw tap voltages (fallback when no hardware)."""
    print("  Hardware not detected. Enter the raw ADS1115 tap voltages")
    print("  from the telemetry log or Grafana debug panel.\n")

    taps = []
    for i in range(NUM_CELLS):
        val = prompt_float(
            f"  Enter raw tap voltage for Channel {i} (e.g., 1.65): ",
            0.01, 6.0, "V"
        )
        taps.append(val)
    return taps


def calibrate_cells(taps):
    """
    Prompt user for cumulative stack voltages measured with a DMM from the
    battery negative to each successive BMS tap, then derive new multipliers.

    The user keeps the BLACK (negative) probe on the battery's main negative
    terminal and moves only the RED (positive) probe to each tap in order.
    This yields cumulative stack voltages that map directly to what the
    resistor ladder measures, making the multiplier math straightforward.
    """
    print_section("STEP 1: Cell Voltage Calibration")

    print("  Set your multimeter to DC Voltage (VDC), typically the 20V range.")
    print()
    print("  Connect the BLACK (negative) probe to the battery's MAIN")
    print("  NEGATIVE terminal (Pack -). Leave it there for all four")
    print("  measurements.")
    print()
    print("  You will move only the RED (positive) probe to each successive")
    print("  BMS cell tap, from Cell 1 (bottom) through Cell 4 (top/Pack +).")
    print()
    print("  Each reading is cumulative — the voltage should increase with")
    print("  each tap. A healthy 4S LiFePO4 pack reads roughly 3.3V, 6.6V,")
    print("  9.9V, and 13.2V at the four taps.")
    print()

    tap_labels = [
        "Tap 1  (Cell 1 top)",
        "Tap 2  (Cell 2 top)",
        "Tap 3  (Cell 3 top)",
        "Tap 4  (Pack +)   ",
    ]
    tap_examples = ["3.32", "6.65", "9.98", "13.31"]

    stack_voltages = []
    for i in range(NUM_CELLS):
        voltage = prompt_float(
            f"  {tap_labels[i]} — enter voltage (e.g., {tap_examples[i]}): ",
            STACK_MIN[i], STACK_MAX[i], "V"
        )

        # Each tap must be higher than the previous
        if stack_voltages and voltage <= stack_voltages[-1]:
            print(f"  [!] Tap {i + 1} ({voltage:.4f}V) must be higher than")
            print(f"      Tap {i} ({stack_voltages[-1]:.4f}V). Please re-measure.")
            print()
            # Re-prompt via recursion-free retry
            while voltage <= stack_voltages[-1]:
                voltage = prompt_float(
                    f"  {tap_labels[i]} — enter voltage (e.g., {tap_examples[i]}): ",
                    STACK_MIN[i], STACK_MAX[i], "V"
                )
                if voltage <= stack_voltages[-1]:
                    print(f"  [!] Must be higher than the previous tap ({stack_voltages[-1]:.4f}V).\n")

        stack_voltages.append(voltage)
        print()

    # Derive individual cell voltages by subtraction (for summary display)
    cell_voltages = [stack_voltages[0]]
    for i in range(1, NUM_CELLS):
        cell_voltages.append(round(stack_voltages[i] - stack_voltages[i - 1], 4))

    # Compute new multipliers: multiplier = stack_voltage / tap_voltage
    new_multipliers = {}
    for i in range(NUM_CELLS):
        key = f"cell{i + 1}"
        if taps[i] <= 0:
            print(f"  [!] Warning: Tap {i} reads 0V — cannot compute multiplier.")
            print(f"      Keeping existing multiplier for {key}.")
            new_multipliers[key] = None
        else:
            new_multipliers[key] = round(stack_voltages[i] / taps[i], 4)

    return cell_voltages, stack_voltages, new_multipliers


def calibrate_shunt():
    """Prompt user for measured shunt resistance and compute correction factor."""
    print_section("STEP 2: Shunt Resistance Calibration")

    print("  *** SAFETY: Completely disconnect power from the system ***")
    print("  *** before measuring the shunt resistor.                ***")
    print()
    print("  Set your multimeter to the LOWEST Ohms/Resistance setting")
    print("  (milliohms if available). Zero/short the leads first.")
    print()
    print("  Place probes directly across the shunt resistor terminals.")
    print()

    measured = prompt_float(
        "  Enter measured shunt resistance in Ohms (e.g., 0.0015 for 1.5m\u03a9): ",
        SHUNT_MIN, SHUNT_MAX, "\u03a9"
    )

    correction_factor = round(NOMINAL_SHUNT_OHMS / measured, 4)

    return measured, correction_factor


def update_telemetry(new_multipliers, correction_factor):
    """Rewrite CELL_MULTIPLIERS and CORRECTION_FACTOR in telemetry.py."""
    with open(TELEMETRY_PATH, "r") as f:
        content = f.read()

    # Build replacement CELL_MULTIPLIERS block
    mult_lines = [
        "CELL_MULTIPLIERS = {",
    ]
    for key, val in new_multipliers.items():
        mult_lines.append(f'    "{key}": {val},')
    mult_lines.append("}")
    mult_block = "\n".join(mult_lines)

    # Replace CELL_MULTIPLIERS dict
    pattern_mult = re.compile(
        r"CELL_MULTIPLIERS\s*=\s*\{[^}]+\}",
        re.DOTALL,
    )
    if not pattern_mult.search(content):
        print("  [!] Could not locate CELL_MULTIPLIERS in telemetry.py")
        return False

    content = pattern_mult.sub(mult_block, content)

    # Replace CORRECTION_FACTOR
    pattern_cf = re.compile(r"CORRECTION_FACTOR\s*=\s*[\d.]+")
    if not pattern_cf.search(content):
        print("  [!] Could not locate CORRECTION_FACTOR in telemetry.py")
        return False

    content = pattern_cf.sub(f"CORRECTION_FACTOR = {correction_factor}", content)

    with open(TELEMETRY_PATH, "w") as f:
        f.write(content)

    return True


def print_summary(cell_voltages, stack_voltages, new_multipliers,
                   measured_shunt, correction_factor):
    """Print a summary of all calibration values."""
    print_section("Calibration Complete")

    print("  Stack Voltages (measured from Pack -):")
    for i, v in enumerate(stack_voltages, start=1):
        print(f"    Tap {i}:   {v:.4f} V")
    print()

    print("  Individual Cell Voltages (derived by subtraction):")
    for i, v in enumerate(cell_voltages, start=1):
        print(f"    Cell {i}:  {v:.4f} V")
    print()

    print("  New Multipliers (written to telemetry.py):")
    for key, val in new_multipliers.items():
        print(f"    {key}:  {val}")
    print()

    print(f"  Measured Shunt Resistance:  {measured_shunt} \u03a9")
    print(f"  New Correction Factor:      {correction_factor}")
    print()

    print("  Restart the telemetry service to apply changes:")
    print()
    print("    sudo systemctl restart gobox_telemetry")
    print()


def main():
    print_banner()

    if not os.path.isfile(TELEMETRY_PATH):
        print(f"  [!] Cannot find telemetry.py at: {TELEMETRY_PATH}")
        print("      Run this script from the repository root directory.")
        sys.exit(1)

    # Read current tap voltages from ADS1115 (or prompt if no hardware)
    print("  Reading ADS1115 tap voltages...")
    print()

    if HAS_HARDWARE:
        try:
            taps = read_tap_voltages()
            print("  Current raw tap readings:")
            for i, t in enumerate(taps):
                print(f"    Channel {i}: {t:.4f} V")
            print()
        except Exception as exc:
            print(f"  [!] Could not read ADS1115: {exc}")
            print("      Falling back to manual entry.\n")
            taps = prompt_tap_voltages()
    else:
        taps = prompt_tap_voltages()

    # Step 1: Cell voltage calibration
    cell_voltages, stack_voltages, new_multipliers = calibrate_cells(taps)

    # Read existing multipliers as fallback for any channels that failed
    with open(TELEMETRY_PATH, "r") as f:
        content = f.read()
    existing = re.findall(r'"(cell\d)":\s*([\d.]+)', content)
    existing_map = {k: float(v) for k, v in existing}

    for key in new_multipliers:
        if new_multipliers[key] is None:
            new_multipliers[key] = existing_map.get(key, 1.0)

    # Step 2: Shunt resistance calibration
    measured_shunt, correction_factor = calibrate_shunt()

    # Write updated values to telemetry.py
    print()
    print("  Writing updated values to telemetry.py...")

    if update_telemetry(new_multipliers, correction_factor):
        print("  Done.")
        print_summary(cell_voltages, stack_voltages, new_multipliers,
                       measured_shunt, correction_factor)
    else:
        print("  [!] Failed to update telemetry.py. Please edit manually.")
        sys.exit(1)


if __name__ == "__main__":
    main()

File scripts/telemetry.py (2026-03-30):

#!/usr/bin/env python3
"""
W7HAK Go Box Telemetry Script
Reads cell voltages from ADS1115 via I2C and temperature from DS18B20 via 1-Wire,
then writes data to a local InfluxDB instance every 10 seconds.

Hardware:
  - Raspberry Pi Zero W
  - ADS1115 ADC at I2C address 0x48
  - DS18B20 temperature sensor on GPIO 4 (1-Wire)
  - 4S3P LiFePO4 battery pack with resistor ladder voltage dividers
  - LTC3780 10A Buck-Boost Converter (calibrated to 14.6V CV / 5A CC)

Current measurement:
  The main current shunt carries bidirectional current.  Positive values
  indicate discharge (system load), negative values indicate charge
  (incoming current from the LTC3780 charger).  The System INA226 at 0x41
  reads this shunt; Grafana queries should account for sign when computing
  net State of Charge (SoC) over time.

Resistor ladder multipliers (to recover actual cell stack voltages from divider output):
  Cell 1 (bottom): 2.0
  Cell 2:          3.2
  Cell 3:          4.3
  Cell 4 (top):    5.7
"""

import time
import glob
import logging
import board
import busio
import adafruit_ads1x15.ads1115 as ADS
from adafruit_ads1x15.analog_in import AnalogIn
import adafruit_ina226
from influxdb import InfluxDBClient

logging.basicConfig(
    level=logging.INFO,
    format="%(asctime)s [%(levelname)s] %(message)s",
)
log = logging.getLogger(__name__)

# --- Configuration ---
INFLUX_HOST = "localhost"
INFLUX_PORT = 8086
INFLUX_DB   = "telemetry"
MEASUREMENT = "battery"

# Resistor ladder multipliers to recover actual cell-stack voltage
CELL_MULTIPLIERS = {
    "cell1": 2.0,
    "cell2": 3.2,
    "cell3": 4.3,
    "cell4": 5.7,
}

# Shunt resistor correction factor — compensates for component tolerances
CORRECTION_FACTOR = 1.025

# 1-Wire sysfs base path for DS18B20
W1_BASE = "/sys/bus/w1/devices"


# --- Helpers ---

def read_ds18b20_temps() -> dict:
    """
    Read all DS18B20 sensors found in the 1-Wire sysfs tree.
    Returns a dict keyed by sensor ID with temperature in Celsius.

    Note: The enclosure contains a hardware thermal switch (~45 °C normally-open)
    wired in series with an RF-silent fan on the DC fuse block.  When DS18B20
    ambient readings approach 45 °C the fan should be observed activating
    independently — no software action is required.
    """
    temps = {}
    sensor_dirs = glob.glob(f"{W1_BASE}/28-*/w1_slave")
    for path in sensor_dirs:
        sensor_id = path.split("/")[-2]
        try:
            with open(path, "r") as f:
                lines = f.readlines()
            if len(lines) >= 2 and "YES" in lines[0]:
                raw = lines[1].strip().split("t=")[-1]
                temps[sensor_id] = round(float(raw) / 1000.0, 2)
            else:
                log.warning("DS18B20 %s: CRC check failed", sensor_id)
        except (OSError, ValueError) as exc:
            log.error("DS18B20 %s read error: %s", sensor_id, exc)
    return temps


def read_cell_voltages(ads) -> dict:
    """
    Read all four single-ended ADS1115 channels and apply resistor ladder
    multipliers to recover actual per-cell stack voltages.

    The ADS1115 measures the voltage at each tap on the resistor ladder;
    subtractive logic gives the voltage contribution of each individual cell.

    Hardware-level RC low-pass filtering (1kΩ / 10µF, cutoff ~16 Hz) is
    implemented on each physical sensor line between the resistor ladder
    output and the ADS1115 input pin.  A parallel 0.1µF ceramic capacitor
    provides additional high-frequency RF decoupling.  This eliminates
    switching noise from the LTC3780 charger at the analog level, so
    aggressive software-side spike filtering is unnecessary.
    """
    # Raw tap voltages (single-ended, referenced to GND)
    # Note: signals are hardware-filtered by RC low-pass before reaching the ADC
    taps = [
        AnalogIn(ads, ADS.P0).voltage,
        AnalogIn(ads, ADS.P1).voltage,
        AnalogIn(ads, ADS.P2).voltage,
        AnalogIn(ads, ADS.P3).voltage,
    ]

    # Recover actual stack voltages using the divider multipliers
    stack = [tap * mult for tap, mult in zip(taps, CELL_MULTIPLIERS.values())]

    # Individual cell voltages via subtraction
    cells = {
        "cell1": round(stack[0], 4),
        "cell2": round(stack[1] - stack[0], 4),
        "cell3": round(stack[2] - stack[1], 4),
        "cell4": round(stack[3] - stack[2], 4),
    }
    return cells


def read_ina226_data(ina_solar, ina_system) -> dict:
    """
    Read bus voltage, corrected current, and power from both INA226 sensors.
    Current is multiplied by CORRECTION_FACTOR to account for shunt resistor tolerances.

    The system INA226 reads bidirectional current through the main shunt:
      - Positive current = discharge (system loads drawing from battery)
      - Negative current = charge (DC-DC charger pushing current into battery)
    Grafana or downstream SoC calculations must preserve the sign to compute
    net energy flow (integral of current over time).

    Hardware-level RC low-pass filtering (1kΩ / 10µF) on the analog sensor
    lines eliminates high-frequency noise at ~16 Hz cutoff, so a lightweight
    rolling average (e.g. 5 samples) in Grafana is sufficient — the script
    does not need aggressive software-side spike filtering.
    """
    return {
        "solar_voltage_v":  round(ina_solar.bus_voltage, 4),
        "solar_current_a":  round(ina_solar.current * CORRECTION_FACTOR, 4),
        "solar_power_w":    round(ina_solar.power, 4),
        "system_voltage_v": round(ina_system.bus_voltage, 4),
        # system_current_a can be negative when the DC-DC charger is active
        "system_current_a": round(ina_system.current * CORRECTION_FACTOR, 4),
        "system_power_w":   round(ina_system.power, 4),
    }


def build_influx_payload(cells: dict, temps: dict, power: dict) -> list:
    fields = {**cells, **power}
    for idx, (sensor_id, temp_c) in enumerate(temps.items(), start=1):
        fields[f"temp{idx}_c"] = temp_c

    return [
        {
            "measurement": MEASUREMENT,
            "fields": fields,
        }
    ]


# --- Main loop ---
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

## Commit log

2026-03-29 pushing existing files
    [33140_3S_4P_CENTER.step, 33140_3S_4P_END_CAP.step]
2026-03-29 Initialize go box telemetry system structure and documentation
    - Reorganize repo into 3d_models/, wiring_diagrams/, scripts/, systemd/
    - Add telemetry.py daemon (ADS1115 cell voltage + DS18B20 temp → InfluxDB)
    - Add setup_pi.sh provisioning script for Raspberry Pi Zero W
    - Add gobox_telemetry.service systemd unit
    - Rewrite README.md with full hardware architecture and deployment guide
    - Add CLAUDE.md with codebase guidance
    [33140_3S_4P_CENTER.step, 33140_3S_4P_END_CAP.step]
2026-03-29 Add INA226 power monitoring and clean up dependencies
    - telemetry.py: add adafruit_ina226 import, CORRECTION_FACTOR constant,
    read_ina226_data() helper (0x40 solar, 0x41 system), wire power data
    into build_influx_payload()
    - setup_pi.sh: replace w1thermsensor pip install with adafruit-circuitpython-ina226
    - CLAUDE.md: document INA226 addresses, CORRECTION_FACTOR, and new InfluxDB fields
    - dashboards/: create directory with placeholder README for Grafana JSON exports
    [telemetry.py]
2026-03-29 Add master wiring guide and fix stale README pip reference
    - wiring_diagrams/WIRING_GUIDE.md: new pin-by-pin guide covering 12V fuse
    block topology, buck converter, I2C bus, 1-Wire bus, USB-C bulkhead test
    pad wiring, and resistor ladder build notes
    - README.md: add "Wiring & Schematics" subsection linking to WIRING_GUIDE.md;
    fix pip install list (w1thermsensor → adafruit-circuitpython-ina226)
2026-03-29 Add Bill of Materials and link from README
2026-03-30 Add interactive calibration script for battery monitoring system
    Creates scripts/calibrate.py that walks users through measuring cell
    voltages and shunt resistance with a DMM, then computes and writes
    corrected CELL_MULTIPLIERS and CORRECTION_FACTOR to telemetry.py.
    Updates README.md with comprehensive calibration documentation.
    https://claude.ai/code/session_01FThf5Cqtf7tA4qaQohVR8L
    [calibrate.py]
2026-03-30 Move Calibration section after Installation and Service Management
    The calibration docs were nested under Hardware Architecture, before
    the user had even installed the software. Relocated to a top-level
    section after Service Management so the README flows logically:
    Hardware → Installation → Service Management → Calibration.
    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
2026-03-30 Change calibration to use cumulative stack voltage probing
    The user keeps the black probe on battery negative and walks the red
    probe up each successive BMS tap, entering cumulative stack voltages
    (~3.3V, ~6.6V, ~9.9V, ~13.2V) rather than individual cell voltages.
    This matches the actual resistor ladder measurement and avoids
    error-prone per-cell probing. Individual cell voltages are derived
    by subtraction and shown in the summary.
    Also adds monotonic validation (each tap must read higher than the
    previous) and updates README to document the correct probing technique.
    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
    [calibrate.py]
2026-03-30 Add DC fuse block, RF-silent fan, and thermal switch documentation
    Integrates three new hardware components across all project docs:
    - DC fuse block with per-load fusing: G90 (10A), buck converter (3A),
    fan circuit (1A), telemetry sensors (1A), fed through a 25A main
    inline fuse from the BMS/shunt.
    - RF-silent 12V DC fan for enclosure cooling, controlled by a
    normally-open ~45 °C bimetallic thermal switch wired in series.
    No GPIO or software control — passive hardware failsafe that
    produces zero RF switching noise on HF.
    Updated files:
    - README.md: new Power Distribution and Thermal Management sections
    - BOM.md: added fan, thermal switch, fuse block, blade fuse assortment
    - WI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
    [telemetry.py]
2026-03-30 Add universal DC charging architecture with buck-boost controller
    Integrates a DC-DC Buck-Boost Charge Controller (14.6V CC/CV LiFePO4
    profile) that accepts 10-30V DC input via an Anderson Powerpole panel
    connector for charging from automotive, vehicle accessory, or bench
    power sources.
    Key design decisions:
    - Charger negative routes through the main current shunt (not direct
    to battery) so the System INA226 reads bidirectional current:
    positive = discharge/load, negative = incoming charge.
    - Charger must be shielded/RF-quiet to avoid HF interference with
    the Xiegu G90.
    - README.md: new Universal DC Charging section, updated ASCII power
    flow diagram showing charger i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
    [telemetry.py]
2026-03-30 Integrate LTC3780 10A buck-boost converter as charger module
    Replaces the generic "DC-DC Buck-Boost Charge Controller" references
    with the specific LTC3780 10A module, physically calibrated to a
    14.6V CV / 5A CC LiFePO4 profile via onboard potentiometers.
    Changes across all docs:
    - README.md: updated ASCII schematic with LTC3780, ferrite toroids,
    and dual 15A fuses; new Charging Calibration section with 3-step
    DMM procedure (CV tuning, CC tuning via 10A meter short, verify);
    updated 3D Models section noting Bambu Lab printed ABS enclosure
    with copper-tape Faraday cage lining
    - BOM.md: added LTC3780 module, 3D-printed enclosure, 2x Mix 31
    ferrite toroids (5-7 turns on input/output)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
    [telemetry.py]
2026-03-30 Add hardware RC low-pass filters for analog telemetry sensor lines
    Adds 1kΩ / 10µF RC low-pass filters (cutoff ~16 Hz) with parallel
    0.1µF ceramic decoupling on each ADS1115 input to eliminate switching
    noise from the LTC3780 and other RF sources at the hardware level.
    - BOM.md: added 4x 1kΩ resistors, 4x 10µF capacitors (25V+ rated),
    4x 0.1µF ceramic decoupling capacitors
    - WIRING_GUIDE.md: new Section 6a with ASCII filter topology diagram,
    placement rules (resistor in series near ADC, caps in parallel to
    ground), design notes on cutoff frequency and ground reference
    - README.md: new Analog Signal Filtering section with topology diagram
    and cutoff frequency exp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
    [telemetry.py]
2026-03-30 Replace output ferrite toroids with LC Pi-Filter on LTC3780
    Implements a high-current LC Pi-Filter on the LTC3780 output that
    eliminates both differential and common-mode RF switching noise:
    Stage 1 (differential): 1000µF electrolytic + 0.1µF ceramic caps
    soldered in parallel directly across LTC3780 OUT terminals.
    Stage 2 (common-mode): Both positive and negative output wires pass
    together through solid ferrite bead(s) (~1cm ID). Critical: passing
    only one wire would saturate the core with 5A DC, defeating the
    filter entirely.
    - README.md: new ASCII schematic showing LC filter topology, updated
    Universal DC Charging section with Stage 1/Stage 2 explanation
    - BOM.md: rep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
2026-03-30 Add KiCad project for custom Pi Zero W telemetry HAT
    Creates pcb/w7hak_hat/ with a KiCad 8 project implementing the
    4-channel cell voltage monitor schematic as a custom Pi Zero W HAT:
    - JST-XH 5-pin connector (J1) for BMS battery cell taps + ground
    - JST-XH 6-pin connector (J2) for ADS1115 ADC module interface
    - 4-channel resistor ladder dividers (47k/33k/22k/10k over 10k)
    - Hardware RC low-pass filters (1kΩ + 10µF/0.1µF) per channel
    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
    [w7hak_hat.kicad_pcb, w7hak_hat.kicad_sch]
2026-04-02 fixes setup and telemetry
    [33140_3S_4P_CENTER.step, 33140_3S_4P_END_CAP.step]
